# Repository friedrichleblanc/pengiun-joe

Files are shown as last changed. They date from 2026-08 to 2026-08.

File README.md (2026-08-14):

# Penguin-joe
## Esp32 based talk-back bot features external custom microphone module.
## Description 
### Motivation
It is good to have companion with you while coding, wathing or ext. And what if that companion is an Penguin joe?

## Hardware Design Decisions
Penguin Joe uses a two-board modular architecture:

Audio in → ESP32 → Cloud APIs → Audio out → Speaker.

This two modules connects to each other by 6-pin, 0.5 mm-pitch FFC/FPC connector and cable.
[For more Information](HardwareDesignDecisions.md)
### Schematics 
[Main](Processor.pdf)  

[Microphone](docs/ICS-43434_Microphone.pdf)

### Main Board

The main board contains the Esp32 processor, XC6220B331MR LDO ,MAX98357A amplifier.

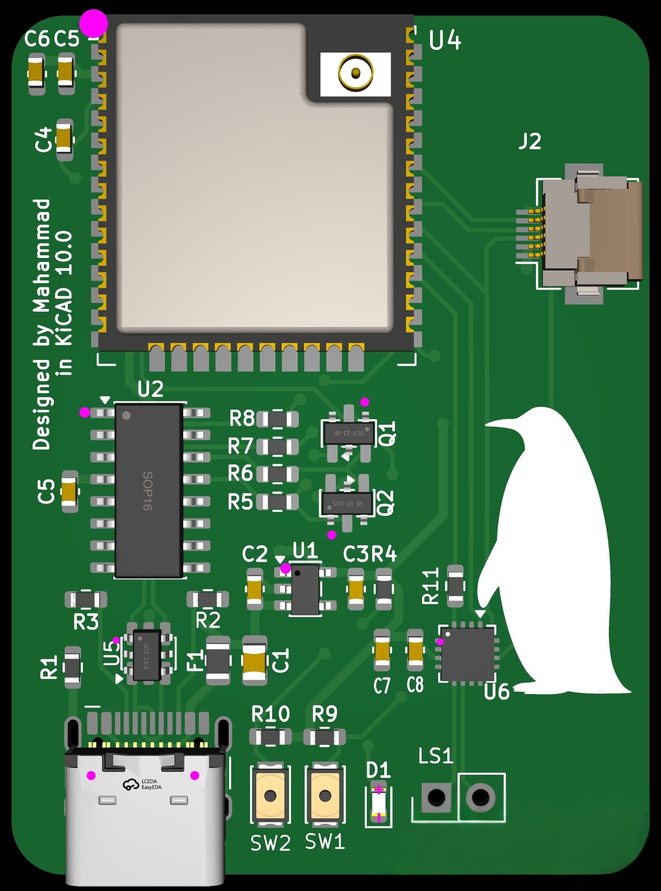
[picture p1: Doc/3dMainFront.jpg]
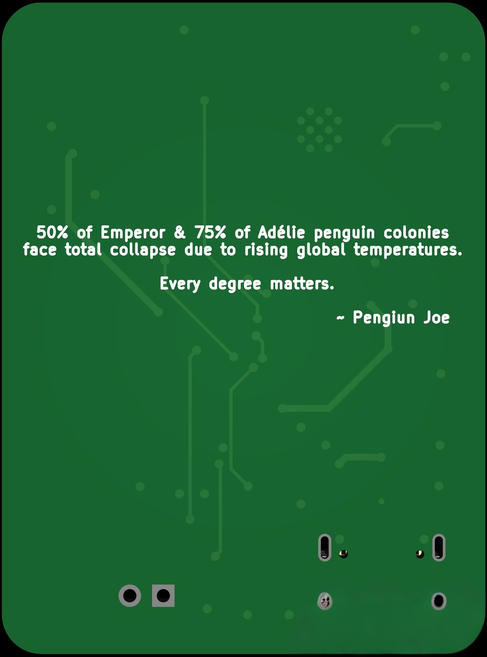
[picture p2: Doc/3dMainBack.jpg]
() () 

### Microphone Board

Separated Microphone MODULE was designed for the placement in shell.

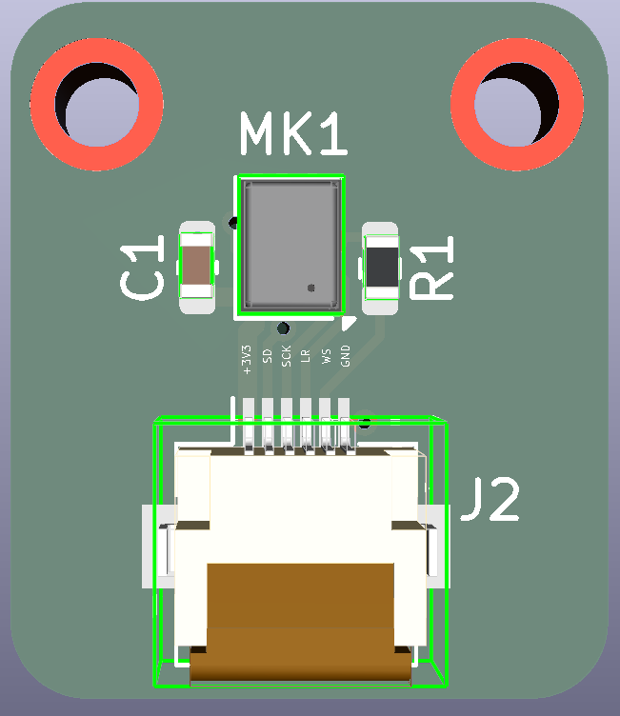
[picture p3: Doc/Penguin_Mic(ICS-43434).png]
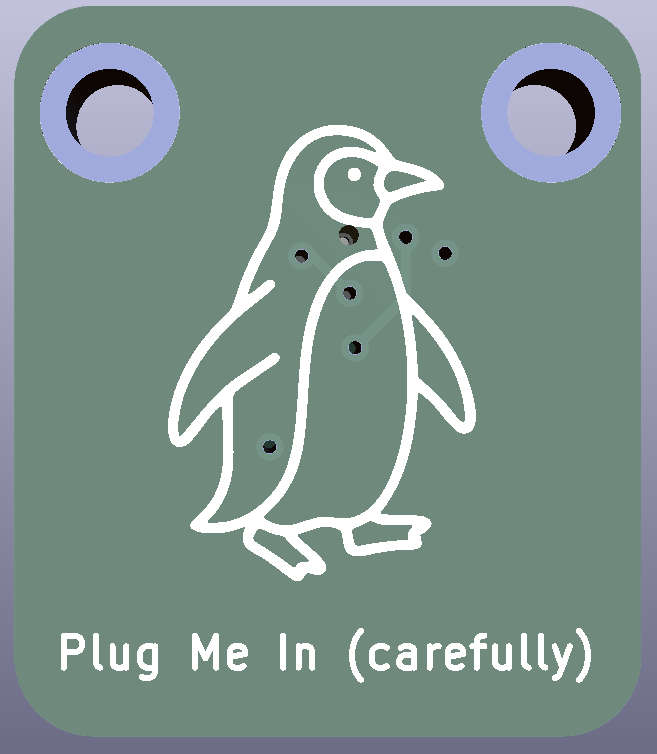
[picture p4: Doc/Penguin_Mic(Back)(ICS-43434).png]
() () 

## Future Improvements
will fix the silk-screen in back of the board has typo(Pengiun joe instead of penguin)
Will add functioning body parts and modules for that design.

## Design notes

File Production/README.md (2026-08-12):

Here, you will find production files to upload to manufacturer. Pick and places are named as positions.csv and bom files from JLCPCB provided.

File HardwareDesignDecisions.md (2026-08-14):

# Hardware Design Decisions

## Main Processor Board

### Main MCU Esp32-wrooom-32u

This board was selected due to having optional use of external antenna that will help capture signals outside of the shell.

### Stackup

4-layer board that has 2 internal GND pours. 

SIGNAL/POWER
GND
GND
SIGNAL/POWER

### Power

USB-C was used for both power and for programming of the MCU. It also provides stable 5V to the so-called Amplifier.

### LDO 

XC6220B331MR was used to reduce voltage from 5V to 3.3V@1A. Parts other than Amplifier connected to this LDO.

### USB-UART

CH340C was used as programmer enhanced with auto-upload circuit

### ESD protection

USBLC6-2SC6 was used in order to prevent Electro-shock off data traces and 5V power trace.

### Amplifier
MAX98357A was selected due to its low cost.

### Hirose FH12 

You may be familiar with similar connector used in PS4 controllers. It was used to connect board to microphone board.

## Microphone board

### Microphone

ICS-43434 is used due to its excellent sound capturing abilities:)

### Hirose FH12 

You may be familiar with similar connector used in PS4 controllers. It was used to connect microphone to the main board.

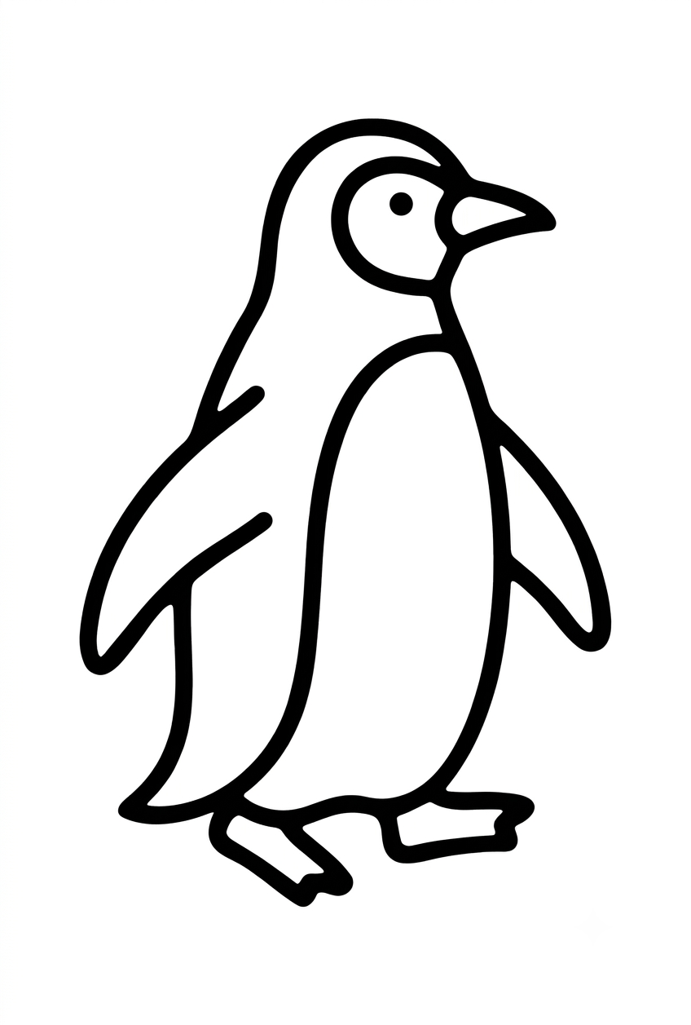
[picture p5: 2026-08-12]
Doc/Penguin_Joe_Silkscreen.png

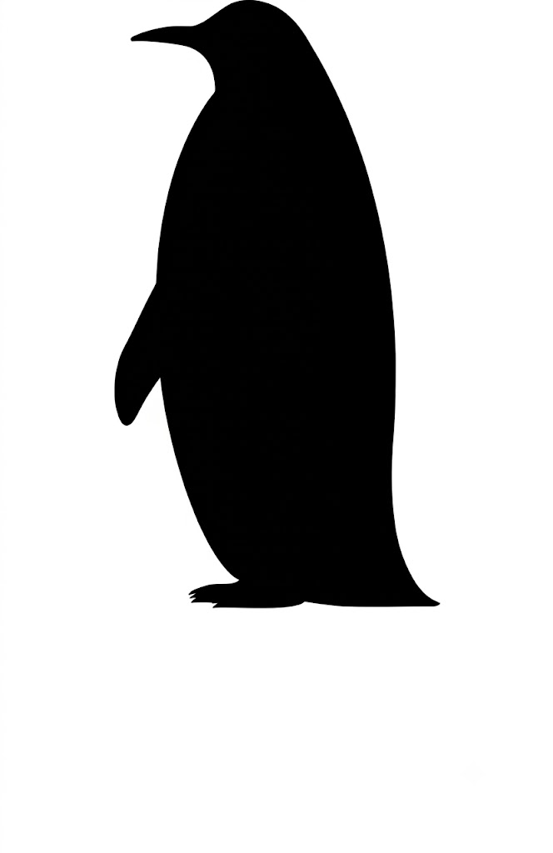
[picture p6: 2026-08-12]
Doc/Penguin_Joe_Main_Silkscreen.jpg

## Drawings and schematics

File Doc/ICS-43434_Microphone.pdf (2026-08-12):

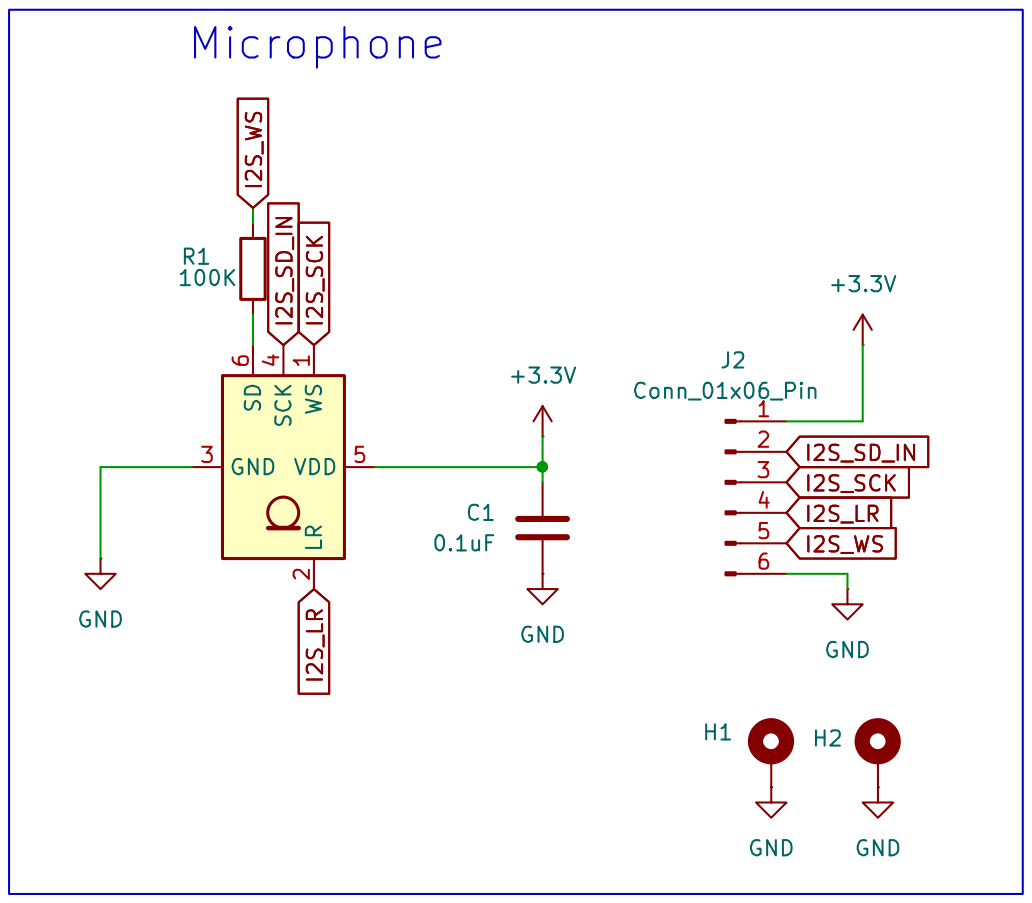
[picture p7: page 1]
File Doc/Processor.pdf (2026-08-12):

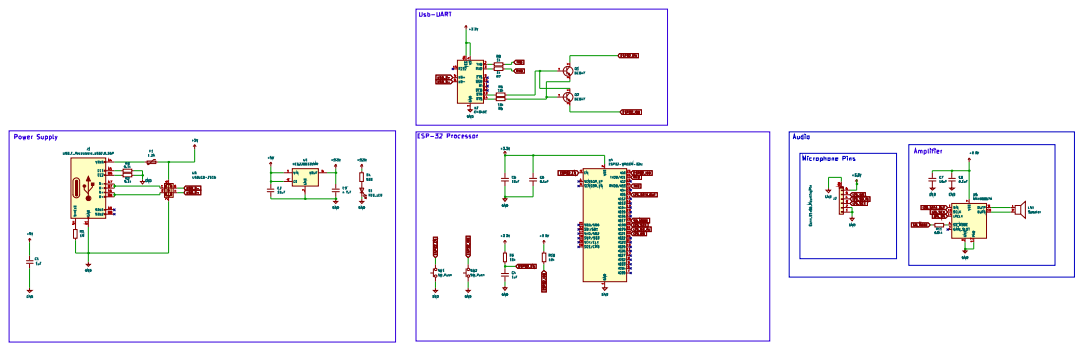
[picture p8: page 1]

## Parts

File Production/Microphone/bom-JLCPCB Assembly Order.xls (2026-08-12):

JLCPCB BOM Tool - BOM Matching
BOM name：bom-JLCPCB Assembly Order.xlsx |  |  | Download Time：2026-08-13 02:13:53 |  |  |  | * Our matching results are updated in real-time, but stock and prices may change. If it's been over 24 hours, please re-match before placing your order.
PCB Assembled Qty：5 |  |  | Est. Total Price：20.8180
Your BOM |  |  |  | Matched Parts |  |  |  |  |  |  | Order Information
Designator | Comment | Footprint | JLCPCB Part # | Matches | Part # | Manufacturer | Footprint | Description | Category | Warning | JLCPCB Part # | Product link | Lib Type | Qty | Source | Total Price ($)
C1 | 0.1uF | 0603 |  | Select by Customer | CL10B104KA8NNNC | Samsung Electro-Mechanics | 0603 | 100nF 25V X7R ±10% 0603 Multilayer Ceramic Capacitors MLCC - SMD/SMT ROHS | Multilayer Ceramic Capacitors MLCC - SMD/SMT |  | C1590 | https://jlcpcb.com/partdetail/1942-CL10B104KA8NNNC/C1590 | Extended | 20 | 20 JLCPCB | 0.218
J2 | Conn_01x06_Pin | Hirose_FH12-6S-0.5SH_1x06-1MP_P0.50mm_Horizontal |  | Select by Customer | FH12-6S-0.5SH(55) | HRS(Hirose) | SMD,P=0.5mm,卧贴 | -40℃~+85℃ 0.3mm 0.5mm 2mm 6P Bottom Contact Gold Hinged Lid Phosphor bronze Surface Mount, Right Angle SMD,P=0.5mm,卧贴 FFC, FPC (Flat Flexible) Connector Assemblies ROHS | FFC, FPC (Flat Flexible) Connector Assemblies |  | C202118 | https://jlcpcb.com/partdetail/HRS_Hirose-FH12_6S_0_5SH_55/C202118 | Extended | 5 | 5 JLCPCB | 1.5745
MK1 | ICS-43434 | InvenSense_ICS-43434-6_3.5x2.65mm |  | Select by Customer | ICS-43434 | TDK InvenSense | LGA-6(3.5x2.7) | -26dB -40℃~+85℃ 0.98mm 1.65V~3.63V 2.65mm 3.5mm 550uA 64dB I2S Omnidirectional Omnidirectional pickup LGA-6(3.5x2.7) MEMS Microphones ROHS | MEMS Microphones |  | C5656610 | https://jlcpcb.com/partdetail/TDKInvenSense-ICS43434/C5656610 | Extended | 5 | 5 JLCPCB | 18.9315
R1 | 100K | 0603 |  | Select by Customer | RC0603FR-07100KL | YAGEO | 0603 | -55℃~+155℃ 100kΩ 100mW 75V Thick Film Resistor ±1% ±100ppm/℃ 0603 Chip Resistor - Surface Mount ROHS | Chip Resistor - Surface Mount | 1.The comment (RC0603FR-07100KL) of this part does not match the one (100K) provided in your BOM. Please confirm; | C14675 | https://jlcpcb.com/partdetail/YAGEO-RC0603FR07100KL/C14675 | Extended | 20 | 20 JLCPCB | 0.094

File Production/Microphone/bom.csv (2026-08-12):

Designator | Footprint | Quantity | Value | LCSC Part #
C1 | 0603 | 1 | 0.1uF
J2 | Hirose_FH12-6S-0.5SH_1x06-1MP_P0.50mm_Horizontal | 1 | Conn_01x06_Pin
MK1 | InvenSense_ICS-43434-6_3.5x2.65mm | 1 | ICS-43434
R1 | 0603 | 1 | 100K

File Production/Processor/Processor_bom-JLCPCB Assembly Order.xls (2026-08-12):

JLCPCB BOM Tool - BOM Matching
BOM name：Talking_Penigun_bom-JLCPCB Assembly Order.xlsx |  |  | Download Time：2026-08-13 01:53:08 |  |  |  | * Our matching results are updated in real-time, but stock and prices may change. If it's been over 24 hours, please re-match before placing your order.
PCB Assembled Qty：5 |  |  | Est. Total Price：39.7849
Your BOM |  |  |  | Matched Parts |  |  |  |  |  |  | Order Information
Designator | Comment | Footprint | JLCPCB Part # | Matches | Part # | Manufacturer | Footprint | Description | Category | Warning | JLCPCB Part # | Product link | Lib Type | Qty | Source | Total Price ($)
C1 | 1uF | 0805 |  | Select by System | CL21B105KBFNNNE | Samsung Electro-Mechanics | 0805 | 1uF 50V X7R ±10% 0805 Multilayer Ceramic Capacitors MLCC - SMD/SMT ROHS | Multilayer Ceramic Capacitors MLCC - SMD/SMT |  | C28323 | https://jlcpcb.com/partdetail/29074-CL21B105KBFNNNE/C28323 | Basic | 20 | 20 JLCPCB | 1.214
C2,C5,C7 | 10uF | 0603 |  | Select by System | CL10A106KP8NNNC | Samsung Electro-Mechanics | 0603 | 10V 10uF X5R ±10% 0603 Multilayer Ceramic Capacitors MLCC - SMD/SMT ROHS | Multilayer Ceramic Capacitors MLCC - SMD/SMT |  | C19702 | https://jlcpcb.com/partdetail/20411-CL10A106KP8NNNC/C19702 | Basic | 25 | 25 JLCPCB | 0.9675
C3 | 4.7uF | 0603 |  | Select by System | CL10A475KO8NNNC | Samsung Electro-Mechanics | 0603 | 16V 4.7uF X5R ±10% 0603 Multilayer Ceramic Capacitors MLCC - SMD/SMT ROHS | Multilayer Ceramic Capacitors MLCC - SMD/SMT |  | C19666 | https://jlcpcb.com/partdetail/20375-CL10A475KO8NNNC/C19666 | Basic | 20 | 20 JLCPCB | 0.664
C4 | 1uF | 0603 |  | Select by System | CL10A105KB8NNNC | Samsung Electro-Mechanics | 0603 | 1uF 50V X5R ±10% 0603 Multilayer Ceramic Capacitors MLCC - SMD/SMT ROHS | Multilayer Ceramic Capacitors MLCC - SMD/SMT |  | C15849 | https://jlcpcb.com/partdetail/16531-CL10A105KB8NNNC/C15849 | Basic | 20 | 20 JLCPCB | 0.544
C5_2,C6,C8 | 0.1uF | 0603 |  | Select by Customer | CL10B104KA8NNNC | Samsung Electro-Mechanics | 0603 | 100nF 25V X7R ±10% 0603 Multilayer Ceramic Capacitors MLCC - SMD/SMT ROHS | Multilayer Ceramic Capacitors MLCC - SMD/SMT | 1.The comment (CL10B104KA8NNNC) of this part does not match the one (0.1uF) provided in your BOM. Please confirm; | C1590 | https://jlcpcb.com/partdetail/1942-CL10B104KA8NNNC/C1590 | Extended | 25 | 25 JLCPCB | 0.2725
D1 | RED_LED | 0603 |  | Select by System | XL-1608SURC-06 | XINGLIGHT | 0603 | -40℃~+85℃ 120° 2.3V 20mA 225mcd 50mW 620nm~630nm 625nm Discrete Diode Red Top-mount Water Clear 0603 LED Indication - Discrete ROHS | LED Indication - Discrete |  | C965799 | https://jlcpcb.com/partdetail/XINGLIGHT-XL_1608SURC06/C965799 | Extended | 20 | 20 JLCPCB | 0.076
F1 | 1.2A | 0805 |  | Select by Customer | MLP2016S1R5MT0S1 | TDK | 0805 | 1.2A 1.5uH 90mΩ Multilayer inductor ±20% 0805 Inductors (SMD) ROHS | Inductors (SMD) |  | C76794 | https://jlcpcb.com/partdetail/TDK-MLP2016S1R5MT0S1/C76794 | Extended | 5 | 5 JLCPCB | 0.523
J1 | USB_C_Receptacle_USB2.0_16P | USB_C_Receptacle_HCTL_HC-TYPE-C-16P-01A |  | Select by Customer | HC-TYPE-C-16P-01A | HCTL | SMD | -55℃~+85℃ 1 16P 20V 5A 7.35mm Black Female Surface Mount, Right Angle Type-C SMD USB Connectors ROHS | USB Connectors |  | C2894897 | https://jlcpcb.com/partdetail/HCTL-HC_TYPE_C_16P01A/C2894897 | Extended | 5 | 5 JLCPCB | 0.496
J2 | Conn_01x06_MountingPin | Hirose_FH12-6S-0.5SH_1x06-1MP_P0.50mm_Horizontal |  | Select by Customer | FH12-6S-0.5SH(55) | HRS(Hirose) | SMD,P=0.5mm,卧贴 | -40℃~+85℃ 0.3mm 0.5mm 2mm 6P Bottom Contact Gold Hinged Lid Phosphor bronze Surface Mount, Right Angle SMD,P=0.5mm,卧贴 FFC, FPC (Flat Flexible) Connector Assemblies ROHS | FFC, FPC (Flat Flexible) Connector Assemblies |  | C202118 | https://jlcpcb.com/partdetail/HRS_Hirose-FH12_6S_0_5SH_55/C202118 | Extended | 5 | 5 JLCPCB | 1.5745
Q1,Q2 | BC847 | SOT-23 |  | Select by Customer | BC847 | Foshan Blue Rocket Elec | SOT-23 | 1 NPN 100mA 15nA 350mW 45V 600mV 6V 800 NPN SOT-23 Bipolar (BJT) ROHS | Bipolar (BJT) |  | C7429759 | https://jlcpcb.com/partdetail/Foshan_Blue_RocketElec-BC847/C7429759 | Extended | 14 | 14 JLCPCB | 0.2562
R1 | 1M | 0603 |  | Select by Customer | 0603WAF1004T5E | UNI-ROYAL(Uniroyal Elec) | 0603 | -55℃~+155℃ 100mW 1MΩ 75V Thick Film Resistor ±1% ±100ppm/℃ 0603 Chip Resistor - Surface Mount ROHS | Chip Resistor - Surface Mount | 1.The comment (0603WAF1004T5E) of this part does not match the one (1M) provided in your BOM. Please confirm; | C22935 | https://jlcpcb.com/partdetail/23662-0603WAF1004T5E/C22935 | Basic | 20 | 20 JLCPCB | 0.198
R2,R3 | 5.1k | 0603 |  | Select by Customer | RC0603JR-075K1L | YAGEO | 0603 | -55℃~+155℃ 100mW 5.1kΩ 75V Thick Film Resistor ±100ppm/℃ ±5% 0603 Chip Resistor - Surface Mount ROHS | Chip Resistor - Surface Mount | 1.The comment (RC0603JR-075K1L) of this part does not match the one (5.1k) provided in your BOM. Please confirm; | C14677 | https://jlcpcb.com/partdetail/YAGEO-RC0603JR075K1L/C14677 | Extended | 20 | 20 JLCPCB | 0.124
R4 | 600 | 0603 |  | Select by Customer | CBG160808U600T | FH (Guangdong Fenghua Advanced Tech) | 0603 | 1 100mA 600mΩ 60Ω@100MHz ±25% 0603 Ferrite Beads ROHS | Ferrite Beads | 1.The comment (CBG160808U600T) of this part does not match the one (600) provided in your BOM. Please confirm; | C1006 | https://jlcpcb.com/partdetail/1358-CBG160808U600T/C1006 | Extended | 20 | 20 JLCPCB | 0.18
R7,R8 | 1k | 0603 |  | Select by Customer | RC0603JR-071KL | YAGEO | 0603 | -55℃~+155℃ 100mW 1kΩ 75V Thick Film Resistor ±100ppm/℃ ±5% 0603 Chip Resistor - Surface Mount ROHS | Chip Resistor - Surface Mount | 1.The comment (RC0603JR-071KL) of this part does not match the one (1k) provided in your BOM. Please confirm; | C14676 | https://jlcpcb.com/partdetail/YAGEO-RC0603JR071KL/C14676 | Extended | 20 | 20 JLCPCB | 0.082
R10,R5,R6,R9 | 10k | 0603 |  | Select by Customer | 0603WAJ0103T5E | UNI-ROYAL(Uniroyal Elec) | 0603 | -55℃~+155℃ 100mW 10kΩ 75V Thick Film Resistor ±100ppm/℃ ±5% 0603 Chip Resistor - Surface Mount ROHS | Chip Resistor - Surface Mount | 1.The comment (0603WAJ0103T5E) of this part does not match the one (10k) provided in your BOM. Please confirm; | C15401 | https://jlcpcb.com/partdetail/16079-0603WAJ0103T5E/C15401 | Extended | 30 | 30 JLCPCB | 0.141
R11 | 634k | 0603 |  | Select by Customer | 0603WAF6343T5E | UNI-ROYAL(Uniroyal Elec) | 0603 | -55℃~+155℃ 100mW 634kΩ 75V Thick Film Resistor ±1% ±100ppm/℃ 0603 Chip Resistor - Surface Mount ROHS | Chip Resistor - Surface Mount | 1.The comment (0603WAF6343T5E) of this part does not match the one (634k) provided in your BOM. Please confirm; | C65831 | https://jlcpcb.com/partdetail/66907-0603WAF6343T5E/C65831 | Extended | 20 | 20 JLCPCB | 0.026
SW1,SW2 | SW_Push | SW_SPST_CK_KXT3 |  | Select by Customer | SKSWCGE010 | ALPSALPINE | SMD,3x2mm | -30℃~+85℃ 0.6mm 12V 2mm 3.37N 300,000 Cycles 3mm 50mA IP67 Round Button SMD(SMT) Tab SPST-NO Surface Mount,Vertical SMD,3x2mm Tactile Switches ROHS | Tactile Switches |  | C255567 | https://jlcpcb.com/partdetail/ALPSALPINE-SKSWCGE010/C255567 | Extended | 12 | 12 JLCPCB | 1.5516
U1 | XC6220B331MR | SOT-23-5 |  | Select by System | XC6220B331MR | TDSEMIC | SOT-23-5 | -20℃~+60℃@(Ta) 1 25uA 280mV@(100mA) 3.3V 300mA 75dB@(1kHz) 7V Enable Fixed Positive SOT-23-5 Voltage Regulators - Linear, Low Drop Out (LDO) Regulators ROHS | Voltage Regulators - Linear, Low Drop Out (LDO) Regulators |  | C22466451 | https://jlcpcb.com/partdetail/TDSEMIC-XC6220B331MR/C22466451 | Extended | 10 | 10 JLCPCB | 0.285
U2 | CH340C | SOIC-16_3.9x9.9mm_P1.27mm |  | Select by System | CH340C | WCH(Jiangsu Qin Heng) | SOP-16 | SOP-16 USB Converters ROHS | USB Converters |  | C7464026 | https://jlcpcb.com/partdetail/WCH_Jiangsu_Qin_Heng-CH340C/C7464026 | Extended | 5 | 5 JLCPCB | 3.1475
U4 | ESP32-WROOM-32U | ESP32-WROOM-32U |  | Select by Customer | ESP32-WROOM-32U-N4 | Espressif Systems | SMD,19.2x18mm | -40℃~+85℃ -97dBm 2.4GHz 20.5dBm 3V~3.6V Bluetooth4.2 ESP32-DOWD UART、SDIO、SPI、I2C、GPIO、PWM、ADC、DAC、CAN SMD,19.2x18mm WiFi Modules ROHS | WiFi Modules | 1.The comment (ESP32-WROOM-32U-N4) of this part does not match the one (ESP32-WROOM-32U) provided in your BOM. Please confirm; | C328062 | https://jlcpcb.com/partdetail/EspressifSystems-ESP32_WROOM_32UN4/C328062 | Extended | 5 | 5 JLCPCB | 20.404
U5 | USBLC6-2SC6 | SOT-23-6 |  | Select by System | USBLC6-2SC6 | TECH PUBLIC | SOT-23-6 | -55℃~+125℃ 0.35pF 12V 150W 2 5V 6A 6V 80nA ESD IEC 61000-4-2、IEC 61000-4-5、IEC 61000-4-4 Unidirectional SOT-23-6 ESD and Surge Protection (TVS/ESD) ROHS | ESD And Surge Protection (TVS/ESD) |  | C2827654 | https://jlcpcb.com/partdetail/TECHPUBLIC-USBLC62SC6/C2827654 | Extended | 9 | 9 JLCPCB | 0.3996
U6 | MAX98357A | TQFN-16-1EP_3x3mm_P0.5mm_EP1.23x1.23mm |  | Select by Customer | MAX98357AETE+T | Analog Devices Inc./Maxim Integrated | TQFN-16-EP(3x3) | -40℃~+85℃ 2.4mA 2.5V~5.5V 3.2Wx1@4Ω 77dB 92% Automatic mute/no-noise switch、Enable/shutdown function、Filterless architecture Class D TQFN-16-EP(3x3) Audio Amplifiers ROHS | Audio Amplifiers | 1.The comment (MAX98357AETE+T) of this part does not match the one (MAX98357A) provided in your BOM. Please confirm; | C910544 | https://jlcpcb.com/partdetail/978950-MAX98357AETET/C910544 | Extended | 5 | 5 JLCPCB | 6.6585
LS1 | Speaker | PinHeader_1x02_P2.54mm_Vertical |  | No matches | No Part Selected

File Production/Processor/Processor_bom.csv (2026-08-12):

Designator | Footprint | Quantity | Value | LCSC Part #
C1 | 0805 | 1 | 1uF
C2, C5, C7 | 0603 | 3 | 10uF
C3 | 0603 | 1 | 4.7uF
C4 | 0603 | 1 | 1uF
C5_2, C6, C8 | 0603 | 3 | 0.1uF
D1 | 0603 | 1 | RED_LED
F1 | 0805 | 1 | 1.2A
J1 | USB_C_Receptacle_HCTL_HC-TYPE-C-16P-01A | 1 | USB_C_Receptacle_USB2.0_16P
J2 | Hirose_FH12-6S-0.5SH_1x06-1MP_P0.50mm_Horizontal | 1 | Conn_01x06_MountingPin
LS1 | PinHeader_1x02_P2.54mm_Vertical | 1 | Speaker
Q1, Q2 | SOT-23 | 2 | BC847
R1 | 0603 | 1 | 1M
R10, R5, R6, R9 | 0603 | 4 | 10k
R11 | 0603 | 1 | 634k
R2, R3 | 0603 | 2 | 5.1k
R4 | 0603 | 1 | 600
R7, R8 | 0603 | 2 | 1k
SW1, SW2 | SW_SPST_CK_KXT3 | 2 | SW_Push
U1 | SOT-23-5 | 1 | XC6220B331MR
U2 | SOIC-16_3.9x9.9mm_P1.27mm | 1 | CH340C
U4 | ESP32-WROOM-32U | 1 | ESP32-WROOM-32U
U5 | SOT-23-6 | 1 | USBLC6-2SC6
U6 | TQFN-16-1EP_3x3mm_P0.5mm_EP1.23x1.23mm | 1 | MAX98357A
